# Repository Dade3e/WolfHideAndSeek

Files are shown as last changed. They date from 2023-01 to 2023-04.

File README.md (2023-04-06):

# WERERABBIT game
## Regole
### Wererabbit
Il gioco è metà tra nascondino e "ce l'hai":
Ogni giocatore ha un arma e i sensori ir,
Minimo di giocatori 3,
Il gioco si divide in wererabbit e rabbits.
Il wererabbit può sparare per passare il suo stato di wererabbit,
i rabbit non possono sparate, solo nascondersi o scappare.

A inizio gioco, il giocatore wererabbit conta per un tempo scelto dal gruppo, gli altri si nascondono.
Ogni giocatore rabbit, ogni circa 10 secondi invia un impulso a 866mhz, il quale è ricevuto dal wererabbit,
che lo visualizza sullo schermo come intensita di segnale trasformata circa in metri e lo aiuterà a cercare i rabbit.

Quando un wererabbit trova e colpisce un rabbit, il colpito diventerà in 60 sec il nuovo wererabbit e il vecchio wererabbit diventerà un rabbit.
Inoltre il vecchio wererabbit è immune al nuovo, ma solo a quello, non ai successivi.

Allo scadere del tempo mostrato a display, perde chi è il wererabbit o lo sta diventando.

### Infected
Ogni giocatore ha un arma e i ricevitori ir.
Il gioco si divide in infetto e sani.

Il gioco inizia con l'infetto che si nasconde.
L'infetto ha il sensore di prossimità il quale vede la distanza dai sani.
Se un sano entra nel raggio dei 5 metri da un infetto, l'infetto può premere il grilletto per infettare il sano.
Se un sano gli spara prima, l'infetto muore.

Il gioco finisce con lo scadere del tempo.
Vincono i più numerosi tra sani e infetti.

### Deathmatch
Classico deathmatch a scquadre o tutti contro tutti,
Se si imposta l'id team a 99, non ci sono squadre e sarà tutti contro tutti.
Una volta colpiti anche solo una volta si muore.
Il gioco finisce allo scadere del tempo.
TODO: vincita?
TODO: tornare alla base per riprendere vita?

### Materiali utilizzati:
- Presa Jack verticale 4 poli: https://www.amazon.it/dp/B089222S84?psc=1&ref=ppx_yo2ov_dt_b_product_details
- EDISION 05-00-0017 Cavo Jack a IR: https://www.amazon.it/dp/B08612KY32?psc=1&ref=ppx_yo2ov_dt_b_product_details
- Esp LoRa32: https://www.amazon.it/dp/B07RWYJQPT?psc=1&ref=ppx_yo2ov_dt_b_product_details
- Led IR SFH 4544: https://it.rs-online.com/web/p/led-a-infrarossi/8108247?sra=pstk
- Transistor 2N2222
- Resistenza da 510/470 Ohm
- Resistenza da 33/27 Ohm
- Pulsante 7 mm: https://www.amazon.it/Gebildet-Precablato-Momentaneo-Temporanei-Ferroviario/dp/B083K1YCZK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
- Finecorsa da usare come grilletto, forse: https://www.amazon.it/InduSKY-Interruttore-Finecorsa-interruttore-Momentaneo/dp/B08736V215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 
- Morsettiera a vite 2.54: https://www.amazon.it/dp/B08VRD69B6?psc=1&smid=A1LEBA88GLK1VX&ref_=chk_typ_imgToDp

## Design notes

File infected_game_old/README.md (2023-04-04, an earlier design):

# Flusso di gioco e protocollo

## Se sei infetto:
Stato 0: Init
idShotMe = myIdPlayer
myValue = stato +1 = 1
Ascolto rivecitore ir e rssi degli altri
TODO: quando premo il grilletto invio il mio stato per infettare

Se vengo colpito con ir,
vado in stato 5
metto myValue in 3
idShotMe = id di chi mi ha colpito

Stato 5:
Stato in cui sto morendo e invio di essere morto
myValue = 3;
idShotMe != mio
2 tentativi invio messaggio:
> invio: mio id 2 char, id di chi mi ha colpito 2 char, mio valore: 3
e mostro schermata colpito ogni secondo
Vado in stato 6, myValue 5

Stato 6:
stato in cui sono morto e aspetto il fine partita
Ricezione stato con lora
invio il mio stato

## Se sei cacciatore

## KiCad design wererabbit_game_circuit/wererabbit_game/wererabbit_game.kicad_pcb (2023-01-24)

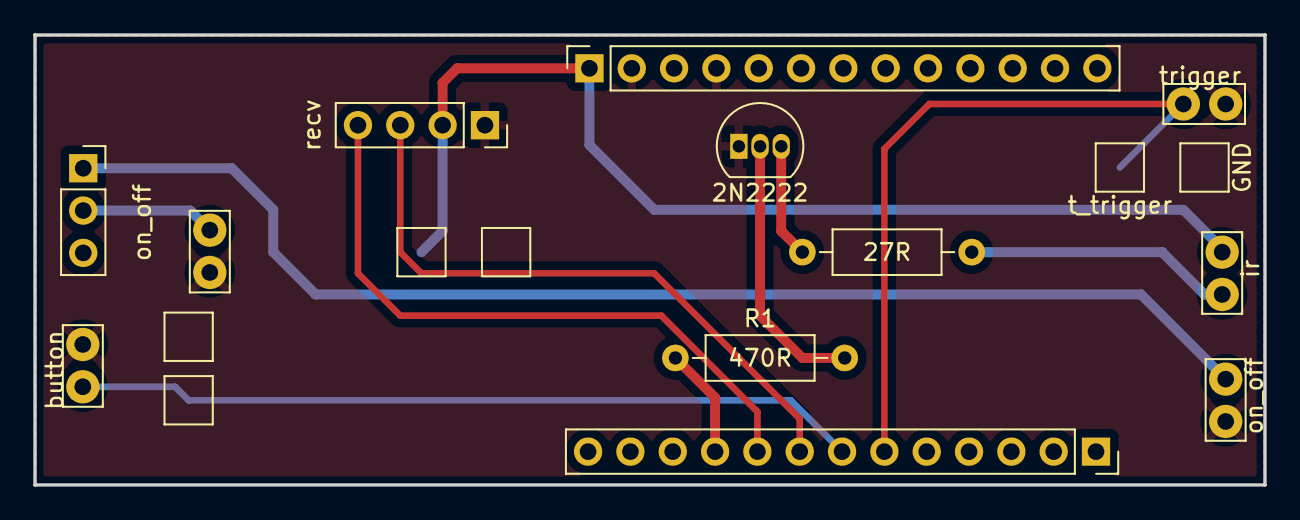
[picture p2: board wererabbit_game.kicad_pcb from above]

Board: 2 copper layers, 73.8 x 27.0 mm, 18 parts (0 on the bottom side), 12 nets.

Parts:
J1, J2: Conn_01x13_Shielded; PinSocket_1x13_P2.54mm_Vertical
J6: ir; TestPoint_Bridge_Pitch2.54mm_Drill1.0mm
J7: trigger; TestPoint_Bridge_Pitch2.54mm_Drill1.0mm
J7a1: t_trigger; TestPoint_Pad_2.5x2.5mm
J8: button; TestPoint_Bridge_Pitch2.54mm_Drill1.0mm
J8a1: t_button; TestPoint_Pad_2.5x2.5mm
J9: recv; PinSocket_1x04_P2.54mm_Vertical
J10, J11: on_off; TestPoint_Bridge_Pitch2.54mm_Drill1.0mm
JGND1, JGND2, JGND3: GND; TestPoint_Pad_2.5x2.5mm
Jvcc1: VCC; TestPoint_Pad_2.5x2.5mm
Q1: 2N2222; TO-92_Inline
R1: 470R; R_Axial_DIN0207_L6.3mm_D2.5mm_P10.16mm_Horizontal
R2: 27R; R_Axial_DIN0207_L6.3mm_D2.5mm_P10.16mm_Horizontal
SW1: SW_DPDT_x2; PinSocket_1x03_P2.54mm_Vertical

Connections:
GND: J2.2, J2.4, J7.1, J8.1, J9.1, J10.1, J11.1, JGND1.1, JGND2.1, JGND3.1, Q1.1 (E)
unnamed: J1.6, J7.1, J7a1.1
unnamed: J1.7, J8.1, J8a1.1
unnamed: J1.8, J9.3
unnamed: J1.9, J9.4
unnamed: J1.10, R1.1
unnamed: J10.1, SW1.1 (A)
unnamed: J11.1, SW1.2 (B)
unnamed: Q1.2 (B), R1.2
unnamed: Q1.3 (C), R2.2
unnamed: J6.1, R2.1
VCC: J2.1, J6.1, J9.2, Jvcc1.1

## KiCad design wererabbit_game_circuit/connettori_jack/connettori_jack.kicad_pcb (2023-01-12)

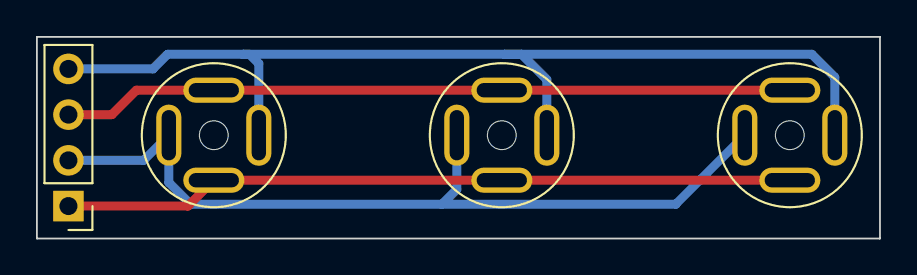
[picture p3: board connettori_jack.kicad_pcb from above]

Board: 2 copper layers, 46.8 x 11.2 mm, 4 parts (0 on the bottom side), 4 nets.

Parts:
J1, J2, J3: AudioJack4; jack_4pins
J4: Conn_01x04; PinHeader_1x04_P2.54mm_Vertical

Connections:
unnamed: J1.3, J2.3, J3.3, J4.3
unnamed: J1.4, J2.4, J3.4, J4.4
unnamed: J1.1, J2.1, J3.1, J4.1
unnamed: J1.2, J2.2, J3.2, J4.2

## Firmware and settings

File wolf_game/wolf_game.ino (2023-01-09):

//Libraries for LoRa
#include <SPI.h>
#include <LoRa.h>

//Libraries for OLED Display
#include <Wire.h>
#include <Adafruit_GFX.h>
#include <Adafruit_SSD1306.h>

//IR
#include <IRrecv.h>
#include <IRsend.h>

//define the pins used by the LoRa transceiver module
#define SCK 5
#define MISO 19
#define MOSI 27
#define SS 18
#define RST 23
#define DIO0 26

//433E6 for Asia
//866E6 for Europe
//915E6 for North America
#define BAND 866E6


//OLED pins
#define OLED_SDA 21  //4
#define OLED_SCL 22 //15
#define OLED_RST -1 //16
#define SCREEN_WIDTH 128 // OLED display width, in pixels
#define SCREEN_HEIGHT 64 // OLED display height, in pixels

Adafruit_SSD1306 display(SCREEN_WIDTH, SCREEN_HEIGHT, &Wire, OLED_RST);



const uint8_t vbatPin = 35;
float VBAT;

int rssi = -124;
long lastRecvTime = millis();
String message_recv = "";

int senders[99];
int senders_rssi[99];

long lastSendTime = 0;        // last send time
long lastCircleTime = 0;
long lastCleanTime = 0;
long lastTriggerTime = 0;
int interval = 2000;          // interval between sends
long msgCount = 0;
int circle_size=12;

//0 recv LUPO, 1 send PREY, 2 sparato ex lupo, 3, 4 colpito come ex lupo, 5 colpito
int stato = 1;

int myPlayerID             = 14;      // Player ID: 0 - 99
int id_wolf                = myPlayerID;
int myValue                = 1;

int triggerState = 0;
int displayOnOff = 1; // 1 acceso

int msg_counter2 = 0;

int ammo = 16;

//Pin declarations
int triggerPin             = 14;
int displayPin             = 21;
int IRtransmitPin          = 2;
int IRreceivePin           = 13;
int speakerPin             = 15;

IRrecv irrecv(IRreceivePin);
decode_results results;
IRsend irsend(IRtransmitPin);



//wolf64: 64x64
const uint8_t PROGMEM wolf64[] = {
0x0, 0x0, 0x0, 0x0, 0x0, 0x0, 0x0, 0xc0, 0x1, 0xf0, 0x0, 0x0, 0x0, 0x0, 0xf, 0xc0, 0x1, 0xfc, 0x0, 0x0, 0x0, 0x0, 0x3f, 0xc0, 0x1, 0xff, 0x0, 0x0, 0x0, 0x0, 0xff,
0xc0, 0x1, 0x9f, 0xc0, 0x0, 0x0, 0x3, 0xfc, 0xc0, 0x1, 0x87, 0xf0, 0x0, 0x0, 0xf, 0xe0, 0xc0, 0x1, 0xc1, 0xfc, 0x0, 0x0, 0x1f, 0x81, 0xc0, 0x1, 0xc0, 0xff, 0x0,
0x0, 0x7e, 0x1, 0x80, 0x0, 0xc0, 0x3f, 0x80, 0x0, 0xfc, 0x1, 0x80, 0x0, 0xc0, 0x1f, 0xc0, 0x41, 0xf8, 0x1, 0x80, 0x0, 0xc0, 0xf, 0xe0, 0xc3, 0xf0, 0x1, 0x80, 0x0,
0xc0, 0x7, 0xf1, 0xc3, 0xe0, 0x1, 0x80, 0x0, 0xc0, 0x3, 0xf3, 0xe7, 0xc0, 0x3, 0x80, 0x0, 0xe0, 0x1, 0xff, 0xff, 0x80, 0x3, 0x80, 0x0, 0x60, 0x0, 0xff, 0xff, 0x80,
0x83, 0x80, 0x0, 0x60, 0x80, 0xff, 0xff, 0x81, 0x83, 0x0, 0x8, 0x60, 0xc1, 0xff, 0xff, 0xe3, 0x83, 0x10, 0xc, 0x60, 0xe7, 0xff, 0xff, 0xff, 0x83, 0x30, 0xe, 0x70,
0xff, 0xff, 0xff, 0xff, 0x83, 0x70, 0xf, 0xf0, 0xff, 0xff, 0xff, 0xff, 0xc7, 0xf0, 0xf, 0xf1, 0xff, 0xcf, 0xf1, 0xff, 0xff, 0xf0, 0x7, 0xff, 0xff, 0xf, 0xf0, 0x3f,
0xff, 0xf0, 0x7, 0xff, 0xfe, 0xf, 0xf0, 0x1f, 0xff, 0xf8, 0x7, 0xff, 0xfc, 0x1f, 0xf8, 0x7, 0xff, 0xfc, 0x7, 0xff, 0xf0, 0x1f, 0xf8, 0x0, 0xf1, 0xfc, 0x7, 0xe3, 0xc0,
0x1f, 0xf8, 0x0, 0x3, 0xfe, 0xf, 0xc0, 0x0, 0x1f, 0xf8, 0x0, 0x7, 0xfe, 0xf, 0xc0, 0x0, 0x1f, 0xf8, 0x0, 0x7, 0xff, 0x1f, 0xe0, 0x0, 0xf, 0xf0, 0x0, 0xf, 0xff, 0x3f,
0xf0, 0x0, 0xf, 0xf0, 0x0, 0x1f, 0xff, 0x7f, 0xf8, 0xf0, 0xf, 0xf0, 0xf, 0x7f, 0xff, 0x7f, 0xff, 0xfc, 0x7, 0xe0, 0x3f, 0xff, 0xff, 0xff, 0xff, 0x86, 0x7, 0xe0, 0x61,
0xff, 0xff, 0xff, 0xfc, 0xc3, 0x7, 0xe0, 0xc3, 0xf, 0xff, 0xff, 0xf8, 0xe1, 0x87, 0xe1, 0x87, 0x7, 0xff, 0xff, 0xf0, 0x70, 0xc7, 0xe3, 0xe, 0x3, 0xfd, 0xdf, 0xe0,
0x38, 0x67, 0xe6, 0x1c, 0x1, 0xfd, 0x9f, 0xe0, 0x1c, 0x77, 0xee, 0x38, 0x1, 0xfc, 0x9f, 0xc0, 0xf, 0xf7, 0xef, 0xf0, 0x0, 0xfc, 0x1f, 0xc0, 0x3, 0xf7, 0xef, 0xc0, 0x0, 0xfc, 0x1f, 0xc0, 0x0, 0xf7, 0xef, 0x0, 0x0,
0xfc, 0x1f, 0xc0, 0x0, 0x37, 0xec, 0x0, 0x1, 0xec, 0x1d, 0xe0, 0x0, 0x7, 0xe0, 0x0, 0x1, 0xec, 0x19, 0xe0, 0x0, 0x7, 0xe0, 0x0, 0xe3, 0xe4, 0x19, 0xf3, 0x80, 0x7, 0xe0, 0x1, 0xf3, 0xe4, 0x11, 0xff, 0xe0, 0x7, 0xe0,
0x3, 0xff, 0xe0, 0x1, 0xff, 0xf0, 0x7, 0xe0, 0x7, 0xff, 0xe0, 0x1, 0xff, 0xf8, 0x7, 0xe0, 0xf, 0xff, 0xe0, 0x1, 0xcf, 0xfc, 0x7, 0xe0, 0x1f, 0xfe, 0xe0, 0x1, 0x8f, 0xfc, 0x7, 0xe0, 0x1f, 0xfc, 0x60, 0x1, 0xf, 0xfe,
0x7, 0xe0, 0x3f, 0xfc, 0x20, 0x0, 0xf, 0xfe, 0x3, 0xc0, 0x3f, 0xdc, 0x0, 0x0, 0xf, 0x7f, 0x3, 0xc0, 0x7f, 0x8c, 0x0, 0x0, 0xe, 0x3f, 0x0, 0x0, 0x7f, 0x4, 0x0, 0x0, 0xc, 0x3f, 0x80, 0x0, 0xfe, 0x4, 0x0, 0x0, 0x8, 
0x1f, 0x80, 0x0, 0xfc, 0x0, 0x0, 0x0, 0x0, 0xf, 0xc0, 0x1, 0xf8, 0x0, 0x0, 0x0, 0x0, 0x7, 0xe0, 0x3, 0xf0, 0x0, 0x0, 0x0, 0x0, 0x3, 0xf0, 0xf, 0xe0, 0x0, 0x0, 0x0, 0x0, 0x1, 0xfc, 0x3f, 0xc0, 0x0, 0x0, 0x0, 0x0, 
0x0, 0x7f, 0xff, 0x80, 0x0, 0x0, 0x0, 0x0, 0x0, 0x3f, 0xfe, 0x0, 0x0, 0x0, 0x0, 0x0, 0x0, 0xf, 0xf8, 0x0, 0x0, 0x0, 0x0, 0x0, 0x0, 0x0, 0x0, 0x0, 0x0, 0x0
};

//wolf40: 40x40
const uint8_t PROGMEM wolf40[] = {
B00001111, B10000000, B00000000, B00000001, B11100000,
B00001000, B11100000, B00000000, B00000111, B00100000,
B00001000, B00110000, B00000000, B00011100, B00100000,
B00000100, B00011100, B00000000, B00111000, B00100000,
B00000100, B00001110, B00000100, B01110000, B00100000,
B00000100, B00000111, B00001100, B11100000, B00100000,
B00000110, B00000011, B11011101, B11000000, B01000000,
B00000010, B00000001, B11111111, B10000010, B01000000,
B00000010, B00100000, B11111111, B00000110, B01001000,
B00100010, B00110011, B11111111, B10001100, B01011000,
B00110010, B00111111, B11111111, B11111110, B11111000,
B00111011, B01111111, B00111100, B01111111, B11111000,
B00011111, B11111100, B01111110, B00001111, B11111000,
B00111111, B11110000, B01111110, B00000001, B11111100,
B00111100, B11000000, B01111110, B00000000, B00011110,
B01111000, B00000000, B01111110, B00000000, B00011110,
B01111100, B00000000, B01111110, B00000000, B00111111,
B01111110, B11100000, B00111100, B00000111, B01111111,
B01111111, B10011000, B00111100, B00011001, B11111111,
B11111111, B10000100, B00111100, B00100001, B11111111,
B11111110, B11000010, B00111100, B01000011, B01111111,
B11111100, B01110001, B00111100, B10001110, B00111111,
B11111100, B00011001, B10111101, B10011000, B00111101,
B10111000, B00001111, B10111101, B11110000, B00011100,
B10111000, B00000011, B10111101, B11000000, B00011100,
B00111000, B00000000, B00111100, B00000000, B00011100,
B00111100, B00000000, B00111100, B00000000, B00110100,
B00111110, B11000000, B00111100, B00000111, B01110000,
B00101111, B11110000, B00111100, B00001111, B11110000,
B00001111, B11111000, B00111100, B00011111, B11010000,
B00001101, B11111000, B00111100, B00011111, B11000000,
B00001001, B11111100, B00111100, B00111111, B01000000,
B00000001, B01111100, B00011000, B00111110, B00000000,
B00000001, B01111110, B00000000, B01111110, B00000000,
B00000000, B00111110, B00000000, B01111100, B00000000,
B00000000, B00011111, B00000000, B11111000, B00000000,
B00000000, B00001111, B10000001, B11110000, B00000000,
B00000000, B00000111, B11000011, B11100000, B00000000,
B00000000, B00000001, B11111111, B10000000, B00000000,
B00000000, B00000000, B11111111, B00000000, B00000000
};

//skull32: 32x32
const uint8_t PROGMEM skull32[] = {
B00000000, B00000111, B11110000, B00000000, 
B00000000, B00111000, B00001110, B00000000, 
B00000000, B01000000, B00000001, B00000000, 
B00000001, B10000000, B00000000, B11000000, 
B00000010, B00000000, B00000000, B00100000, 
B00000100, B00000000, B00000000, B00010000, 
B00000100, B00000000, B00000000, B00010000, 
B00001000, B00000000, B00000000, B00001000, 
B00010000, B00000000, B00000000, B00000100, 
B00010000, B00000000, B00000000, B00000100, 
B00010000, B00000000, B00000000, B00000100, 
B00100000, B01110000, B00000111, B00000010, 
B00100001, B11111100, B00011111, B11000010, 
B00100001, B11111100, B00011111, B11000010, 
B00100011, B11111110, B00111111, B11100010, 
B00100011, B11111110, B00111111, B11100010, 
B00100011, B11111110, B00111111, B11100010, 
B00100001, B11111100, B00011111, B11000010, 
B00010001, B11111100, B00011111, B11000100, 
B00010000, B01110000, B00000111, B00000100, 
B00010000, B00000000, B00000000, B00000100, 
B00001000, B00000000, B00000000, B00001000, 
B00000100, B00000000, B00000000, B00010000, 
B00000100, B00000000, B00000000, B00010000, 
B00000010, B00000000, B00000000, B00100000, 
B00000001, B10000000, B00000000, B11000000, 
B00000000, B10000000, B00000000, B10000000, 
B00000000, B10001000, B10001000, B10000000, 
B00000000, B10001000, B10001000, B10000000, 
B00000000, B11111111, B11111111, B10000000, 
B00000000, B00000000, B00000000, B00000000, 
B00000000, B00000000, B00000000, B00000000
};

//wolf32: 32x32
const uint8_t PROGMEM wolf32[] = {
B00000111, B00000000, B00000001, B11000000, 
B00000101, B10000000, B00000011, B01000000, 
B00000100, B11000000, B00000110, B01000000, 
B00000100, B11110000, B10001100, B01000000, 
B00000110, B01111001, B10011000, B01000000, 
B00000010, B00111101, B10110000, B11000000, 
B00000010, B00011111, B11110010, B10000000, 
B00010010, B10111111, B11111010, B10010000, 
B00011011, B11110111, B11011110, B10110000, 
B00011111, B11100111, B11000111, B11110000, 
B00011111, B00000111, B11000001, B11111000, 
B00111100, B00000111, B11000000, B11111000, 
B00111100, B00000011, B10000000, B11111100, 
B01111100, B11000011, B10000110, B11111100, 
B01111111, B11100011, B10001101, B01111100, 
B01111100, B00110011, B10011000, B01110100, 
B01101100, B10011011, B10110010, B01110000, 
B01001000, B01001011, B10100100, B01111000, 
B01011100, B00111011, B10111000, B01111000, 
B01011101, B00000011, B10000000, B00111000, 
B00011111, B00000011, B10000001, B10101000, 
B00011111, B10000011, B10000011, B11100000, 
B00010111, B10000011, B10000111, B11100000, 
B00000111, B11000011, B10001111, B11100000, 
B00000011, B11100001, B00001111, B01100000, 
B00000011, B11100000, B00011110, B00100000, 
B00000010, B11111000, B00011110, B00000000, 
B00000000, B00111100, B00111000, B00000000, 
B00000000, B00001111, B11110000, B00000000, 
B00000000, B00000011, B11000000, B00000000,
B00000000, B00000000, B00000000, B00000000,
B00000000, B00000000, B00000000, B00000000
};

//Rabbit 16x16
const uint8_t PROGMEM rabbit16[]{
B00001100, B00110000,
B00011110, B01111000, 
B00010010, B01001000,
B00010010, B01001000, 
B00010010, B01001000, 
B00010010, B01001000, 
B00010010, B01001000, 
B00010110, B01101000, 
B00011011, B11011000,
B00110101, B10101100, 
B00111011, B11011100, 
B00111111, B11111100, 
B00111010, B01011100, 
B00011000, B00011000, 
B00001111, B11110000, 
B00000000, B00000000
};

//infinity 16x6
const uint8_t PROGMEM infin[]{
B00011100, B00111000,
B00100010, B01000100,
B01000001, B10000010,
B01000001, B10000010,
B00100010, B01000100,
B00011100, B00111000
};

//infinity 16x5
const uint8_t PROGMEM little_infin[]{
B00011100, B00111000,
B00100010, B01000100,
B00100001, B10000100,
B00100010, B01000100,
B00011100, B00111000
};


//bullet 8X16
const uint8_t PROGMEM bullet8X16[]{
B00011000, 
B00111100, 
B00110100, 
B01110010, 
B01110010, 
B11111111, 
B11111111, 
B11110011, 
B11110011, 
B11110011, 
B11110011, 
B11110011, 
B11110011, 
B11110011, 
B01111110, 
B11111111
};
//bullet 9X20
const uint8_t PROGMEM bullet8X20[]{
0x18, 0x3c, 0x3c, 0x7a, 0x7a, 0x7e, 0xff, 0xfd, 0xf9, 0xf9, 0xf9, 0xf9, 0xf9, 0xf9, 0xf9, 0xf9, 0xfd, 0xff, 0x7e, 0xff,
};


void setup() { 
  //initialize Serial Monitor
  Serial.begin(115200);
  pinMode(vbatPin, INPUT);
  //reset OLED display via software

  pinMode(triggerPin, INPUT_PULLUP);
  pinMode(displayPin, INPUT_PULLUP);
  pinMode(speakerPin, OUTPUT);
  pinMode(IRtransmitPin, OUTPUT);
  pinMode(IRreceivePin, INPUT);

  digitalWrite(triggerPin, HIGH);      // Not really needed if your circuit has the correct pull up resistors already but doesn't harm

  irsend.begin();
  irrecv.enableIRIn(); // Start the receiver

  pinMode(OLED_RST, OUTPUT);
  digitalWrite(OLED_RST, LOW);
  delay(20);
  digitalWrite(OLED_RST, HIGH);
  
  //initialize OLED
  Wire.begin(OLED_SDA, OLED_SCL);
  if(!display.begin(SSD1306_SWITCHCAPVCC, 0x3c, false, false)) { // Address 0x3C for 128x32
    Serial.println(F("SSD1306 allocation failed"));
    for(;;); // Don't proceed, loop forever
  }

  //display.ssd1306_command(SSD1306_DISPLAYON);
  display.ssd1306_command(0x81);
  display.ssd1306_command(0x01);
  //display.dim(true);

  display.clearDisplay();
  display.setTextColor(WHITE);
  display.drawBitmap(0, 0, wolf64, 64, 64, WHITE);
  display.setTextSize(1);
  display.setCursor(76,10);
  display.print("WOLF");
  display.setCursor(76,30);
  display.print("HIDE and");
  display.setCursor(76,50);
  display.print("SEEK");
  display.display();


//SPI LoRa pins
  SPI.begin(SCK, MISO, MOSI, SS);
  //setup LoRa transceiver module
  LoRa.setPins(SS, RST, DIO0);

  if (!LoRa.begin(BAND)) {
    Serial.println("Starting LoRa failed!");
    while (1);
  }

  LoRa.setTxPower(2);
  Serial.println("LoRa Initializing OK!");
  delay(3000);
  Serial.println("Setup OK!");
}

void loop() {
  //display.drawLine()
  // see if a packet was received
  
  gestioneDisplayOnOff();

  if(stato == 0){
    //RECV and SHOOT
    attesa_msg();
    if((millis()-lastSendTime)>1000){
      lastSendTime = millis();
      VBAT = (float)(analogRead(vbatPin)) / 4095*2*3.3*1.1;
      if(displayOnOff == 1 && triggerState == 0)
        schermata_recv_draws();
    }
    if((millis()-lastCleanTime)>60000){
      lastCleanTime = millis();
      memset(senders, 0, sizeof(senders));
    }
    if(triggerState == 0 && digitalRead(triggerPin) == LOW){
      shoot();
      if(displayOnOff == 1)
        schermata_shoot();
      triggerState = 1;
      ammo--;
      if(ammo <= 0)
        ammo = 16;
    }
    gestioneTrigger();
    
  }

  if(stato == 1){
    //SEND
    receiveIR();
    if (millis() - lastSendTime > interval) {
      sendMessage();
      VBAT = (float)(analogRead(vbatPin)) / 4095*2*3.3*1.1;
      lastSendTime = millis();            // timestamp the message
      interval = random(3000) + 9000;    // 9 - 12 seconds
      circle_size = 12;
    }
    if (millis() - lastCircleTime > 300) {
        if(displayOnOff == 1)
          schermata_send();
      lastCircleTime = millis();
    }
  }

  //rivecuto che ho colpito un ex lupo  
  if(stato == 2){
    
    if((millis()-lastCleanTime)>3000){
      lastCleanTime = millis();
      stato = 0; // TORNO LUPO
    }
  }

  //colpito 
  if(stato == 3){
    if((millis()-lastCleanTime)>3000){
      lastCleanTime = millis();
      stato = 1; //DIVENTO PREY
    }
  }

  //colpito ma sono ex lupo
  if(stato == 4){
    stato = 1; //RIMANGO PREY
    myValue = 2; //invio segnale che ero ex lupo
    int j = 0;
    while(j < 3){
      if (millis() - lastSendTime > interval) {
        sendMessage();
        VBAT = (float)(analogRead(vbatPin)) / 4095*2*3.3*1.1;
        lastSendTime = millis();            // timestamp the message
        interval = random(3000) + 9000;    // 9 - 12 seconds
        circle_size = 12;
        j++;
      }
      if (millis() - lastCircleTime > 300) {
        schermata_send_wolf();
        lastCircleTime = millis();
      }
    }
    myValue = 1;
  }

  //Sono stato colpito
  if(stato == 5){
    stato = 0; //DIVENTO LUPO
    myValue = 3;
    int j = 0;
    int swap = 0;
    while(j < 4){
      if (millis() - lastSendTime > interval) {
        sendMessage();
        VBAT = (float)(analogRead(vbatPin)) / 4095*2*3.3*1.1;
        lastSendTime = millis();            // timestamp the message
        interval = random(3000) + 9000;    // 9 - 12 seconds
        circle_size = 12;
        j++;
      }
      if (millis() - lastCircleTime > 1500) {
        schermata_colpito(swap);
        VBAT = (float)(analogRead(vbatPin)) / 4095*2*3.3*1.1;
        
        lastCircleTime = millis();
        swap++;
      }
    }
    myValue = 1; 
  }
}


//gestione display ON OFF
int displayState = 0;
int exDisplayState = 0;
long lastDisplayOnOffTime = 0;

void gestioneDisplayOnOff(){
  if((millis()-lastDisplayOnOffTime)>100){
    lastDisplayOnOffTime = millis();
    
    exDisplayState = displayState;
    displayState = digitalRead(displayPin);
    if(displayState == 0 && exDisplayState != displayState){
      exDisplayState = displayState;
      displayOnOff = displayOnOff * -1 + 1;
      display.ssd1306_command(SSD1306_DISPLAYOFF+displayOnOff);
      schermata_nera();
    }
  }
}

void gestioneTrigger(){
  if((millis()-lastTriggerTime)>100){
    lastTriggerTime = millis();
    if(digitalRead(triggerPin) == HIGH ){
      triggerState = 0;
    }
  }
}

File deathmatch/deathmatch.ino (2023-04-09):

//Libraries for LoRa
#include <SPI.h>
#include <LoRa.h>

//Libraries for OLED Display
#include <Wire.h>
#include <Adafruit_GFX.h>
#include <Adafruit_SSD1306.h>

//IR
#include <IRrecv.h>
#include <IRsend.h>

#include "./variables.h"
#include "./icons.h"


Adafruit_SSD1306 display(SCREEN_WIDTH, SCREEN_HEIGHT, &Wire, OLED_RST);

IRrecv irrecv(IRreceivePin);
decode_results results;
IRsend irsend(IRtransmitPin);


void setup() { 
  //initialize Serial Monitor
  Serial.begin(115200);
  pinMode(vbatPin, INPUT);

  pinMode(triggerPin, INPUT_PULLUP);
  pinMode(displayPin, INPUT_PULLUP);
  pinMode(speakerPin, OUTPUT);
  pinMode(IRtransmitPin, OUTPUT);
  pinMode(IRreceivePin, INPUT);

  digitalWrite(triggerPin, HIGH);
  digitalWrite(displayPin, HIGH);
  digitalWrite(speakerPin, HIGH);

  irsend.begin();
  irrecv.enableIRIn();

  pinMode(OLED_RST, OUTPUT);
  digitalWrite(OLED_RST, LOW);
  delay(20);
  digitalWrite(OLED_RST, HIGH);
  
  //initialize OLED
  Wire.begin(OLED_SDA, OLED_SCL);
  if(!display.begin(SSD1306_SWITCHCAPVCC, 0x3c, false, false)) {
    Serial.println(F("SSD1306 allocation failed"));
    for(;;);
  }

  //display.ssd1306_command(SSD1306_DISPLAYON);
  display.ssd1306_command(0x81);
  display.ssd1306_command(0x01);
  //display.dim(true);

//SPI LoRa pins
  SPI.begin(SCK, MISO, MOSI, SS);
  //setup LoRa transceiver module
  LoRa.setPins(SS, RST, DIO0);

  if (!LoRa.begin(BAND)) {
    Serial.println("Starting LoRa failed!");
    while (1);
  }
  LoRa.setSpreadingFactor(spreadingFactor);
  LoRa.setTxPower(txPower);

  Serial.println("LoRa Initializing OK!");

  first_frame();

  Serial.println("Setup OK!");
  digitalWrite(speakerPin, LOW);
}


void loop() {

  gestioneDisplayOnOff();
  triggerRelease();

  if(gameTimer == gameTime){
    Serial.println("START GAME!");
    first_frame();
    waitStartGame();
    //quando esce inizio a giocare
    gameTimer -= 1;
  }

  if((millis() - lastGameTime) > 1000){
    lastGameTime = millis();
    gameTimer -= 1;
  }

  if(gameTimer <= 0){
    Serial.println("END GAME!");
    fineGioco();
    waitStartGame();
    gameTimer == gameTime;
  }

  //Sono IN GAME
  if(gameState == 1){
    //SONO IN GAME, ascolto ricevitore ir e rssi degli altri
    receiveIR();
    lora_recv();
    if((millis()-lastCleanTime)>1000){
      lastCleanTime = millis();
      VBAT = (float)(analogRead(vbatPin)) / 4095*2*3.3*1.1;
      if(displayOnOff == 1 && triggerState == 0)
        schermata_ammo();
    }
    if (millis() - lastSendTime > interval) {
      sendMessage();
      VBAT = (float)(analogRead(vbatPin)) / 4095*2*3.3*1.1;
      lastSendTime = millis();            // timestamp the message
      interval = random(3000) + minSendTime;    // 60 - 63 seconds
    }

    if(triggerState == 0 && digitalRead(triggerPin) == LOW && ammo > 0){
      shoot();
      triggerState = 1;
      ammo--;
      if(ammo <= 0)
        ammo = 16;
      if(displayOnOff == 1)
        schermata_ammo();
    }
  }

  //Stato APPENA COLPITO
  if(gameState == 2){
    //per_chi = 13;
    //invio di essermi infettato e aspetto risposta per 3 sec e provo per 2 volte
    int j = 0;
    sendMessage();
    schermata_colpito();
    lastSendTime = millis();
    while(j < 2 && gameState == 2){
      lora_recv();
      if (millis() - lastSendTime > interval) {
        sendMessage();
        VBAT = (float)(analogRead(vbatPin)) / 4095*2*3.3*1.1;
        lastSendTime = millis();
        interval = random(1000) + 3000;    // 3 - 4 seconds
        j++;
      }
    }
    lastSendTime = millis();
    gameState = 3;            //se metto 1 diventa un tester, 3 normale
    digitalWrite(speakerPin, LOW);
  }

  //sono MORTO
  if(gameState == 3){
    lora_recv(); // aggiorno valori giocatori
    digitalWrite(speakerPin, blink);
    if (millis() - lastCleanTime > 1000) {
      if(displayOnOff == 1)
        schermata_wait();
      lastCleanTime = millis();
      blink = (blink *-1) +1;
    }
    if (millis() - lastSendTime > interval) {
      sendMessage();
      VBAT = (float)(analogRead(vbatPin)) / 4095*2*3.3*1.1;
      lastSendTime = millis();            // timestamp the message
      interval = random(3000) + minSendTime;    // 9 - 12 seconds
    }
  }

  //stato di PROVA
  if(gameState == 9){
    VBAT = (float)(analogRead(vbatPin)) / 4095*2*3.3*1.1;
    //schermata_HIT();
    //schermata_colpito();
    //schermata_infettato();
    schermata_lose();
    //schermata_wait();
    delay(300);
  }

}

void waitStartGame(){
  Serial.println("Wait trigger!");
  
  delay(100);
  int exit = 0;
  triggerState = 0;
  unsigned long tempo_start = millis();
  while(exit == 0){
    if(triggerState == 0 && digitalRead(triggerPin) == LOW){
      triggerState = 1;
      tempo_start = millis();
    }
    if((millis()-lastTriggerTime)>100){
      lastTriggerTime = millis();
      if(triggerState == 1 && digitalRead(triggerPin) == HIGH){
        if(millis() - tempo_start > 2000)
          exit = 1;
      }
    }
  }
  triggerState = 0;
}
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

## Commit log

2023-01-04 Add files
    Aggiunti tutti i file, il prototipo cosi funziona
2023-01-10 corretto bug id e migliorata distanza
    [lora_part.ino]
2023-01-12 Aggiunti schematici
    [connettori_jack-B_Cu.gbr, connettori_jack-B_Mask.gbr, connettori_jack-B_Silkscreen.gbr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]
2023-01-12 Readme con materiali usati
2023-01-12 Aggiunto timer e pulizia array
    Ho implementato il timer di gioco e trovato il modo di pulire ogni 30 sec e che i coniglietti siano circa sempre visibili, pulendo appena prima di reinserire un coniglietto.
2023-01-12 start up con grilletto
    il gioco inizia se si preme per 2 sec e rilascia il grilletto
2023-01-15 aggiunto stato 2
    nel gioco infetti per mostrare la schermata che hai infettato ho aggiunto lo stato 2
2023-01-24 Aggiunto scritte alla pcb
    [wererabbit_game.kicad_pcb]
2023-04-06 Aggiunta gestione led
2023-04-08 Corretto led e comunicazione lora
